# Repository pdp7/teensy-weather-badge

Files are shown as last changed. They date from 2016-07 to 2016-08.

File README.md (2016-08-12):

# teensy-weather-badge
Weather badge with Teensy 3.2 or LC, Adafruit 128x32 OLED (i2c) and Adafruit BME280 (i2c)

## Shared Project:
* [OSH Park: Ab57il2e](https://oshpark.com/shared_projects/Ab57il2e)

## Bill of Materials:
* [Adafruit I2C OLED (128x32)](https://www.adafruit.com/product/931)
* [Adafruit I2C BME280 (temp/hum/press)](https://www.adafruit.com/product/2652)
* Teensy:
   * Option 1: [Teensy 3.2 - OSH Park Edition](https://oshpark.com/teensy)
  * Option 2: [Teensy LC - OSH Park Edition](http://store.oshpark.com/products/teensy-lc)

## Photos:
* [instagram](https://www.instagram.com/p/BHsfERNAH9x/?taken-by=oshpark)
* [twitter](https://twitter.com/pdp7/status/762103242037886977)

## License
This project released under the CERN Open Hardware v1.2 License

**Note:** `teensy-weather-badge.ino` contains code written by Limor Fried & Kevin Townsend for Adafruit Industries and is covered by BSD license

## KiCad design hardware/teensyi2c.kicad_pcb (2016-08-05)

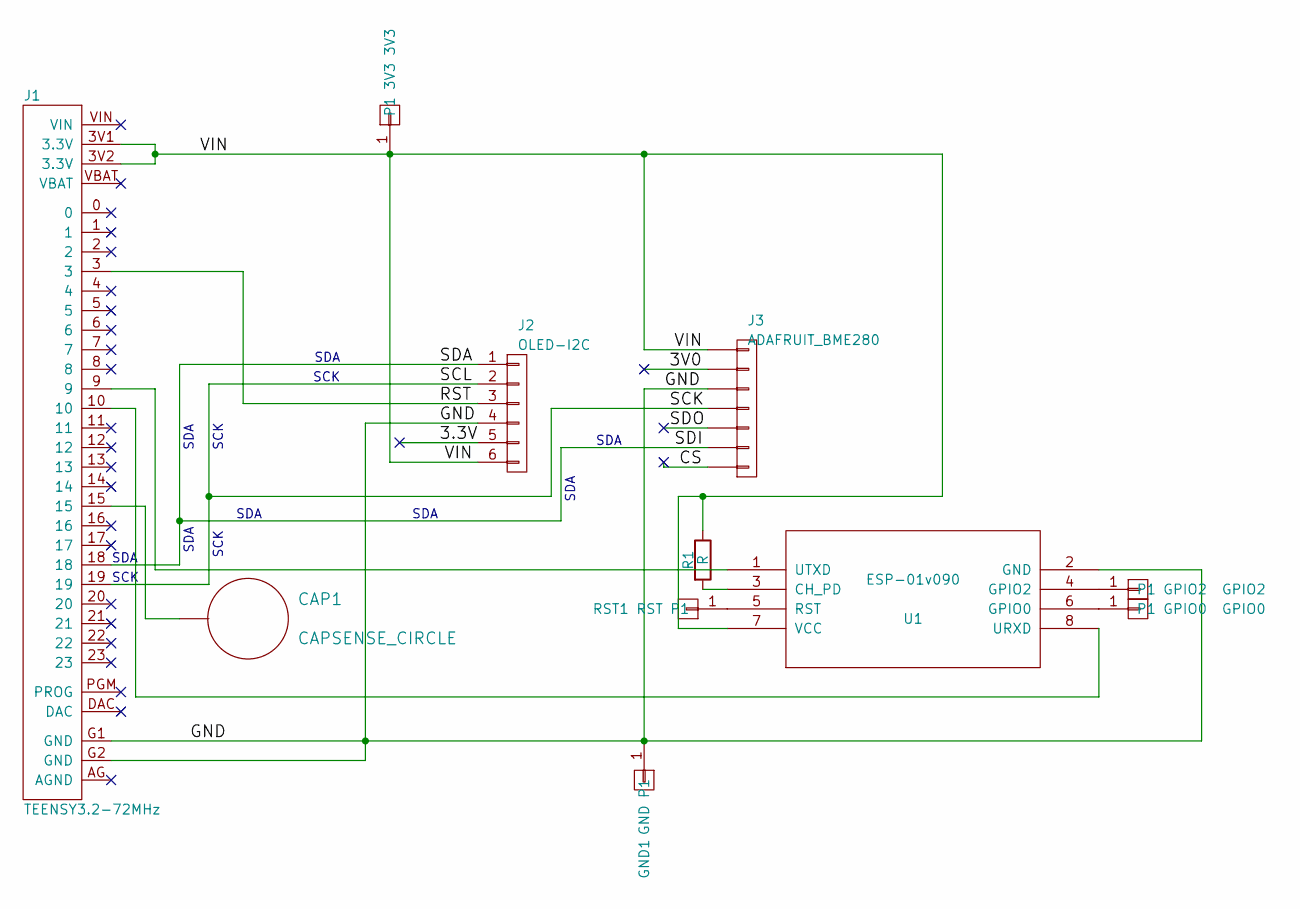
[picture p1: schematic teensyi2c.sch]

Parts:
3V3: 3V3; Pin_Header_Straight_1x01
CAP1: CAPSENSE_CIRCLE; CAPSENSE_CIRCLE_D10
GND1: GND; Pin_Header_Straight_1x01
GPIO0: GPIO0; Pin_Header_Straight_1x01
GPIO2: GPIO2; Pin_Header_Straight_1x01
J1: TEENSY3.2-72MHz; TEENSY-3.2
J2: OLED-I2C; Pin_Header_Straight_1x06
J3: ADAFRUIT_BME280; Pin_Header_Straight_1x07
R1: R; Resistor_Horizontal_RM7mm
RST1: RST; Pin_Header_Straight_1x01
U1: ESP-01v090; ESP-01

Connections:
/3.3V: J2.5
/3V0: J3.2
/CS: J3.7
/GND: GND1.1, J1.G1 (GND), J1.G2 (GND), J2.4, J3.3, U1.2 (GND)
/RST: J1.3, J2.3
/SCK: J1.19, J2.2, J3.4
/SDA: J1.18, J2.1, J3.6
/SDO: J3.5
/VIN: 3V3.1, J1.3V1 (3.3V), J1.3V2 (3.3V), J2.6, J3.1, R1.1, U1.7 (VCC)
unnamed: CAP1.1, J1.15
unnamed: GPIO0.1, U1.6 (GPIO0)
unnamed: GPIO2.1, U1.4 (GPIO2)
unnamed: J1.9, U1.1 (UTXD)
unnamed: J1.10, U1.8 (URXD)
unnamed: R1.2, U1.3 (CH_PD)
unnamed: RST1.1, U1.5 (RST)

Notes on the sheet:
SCK
SDA

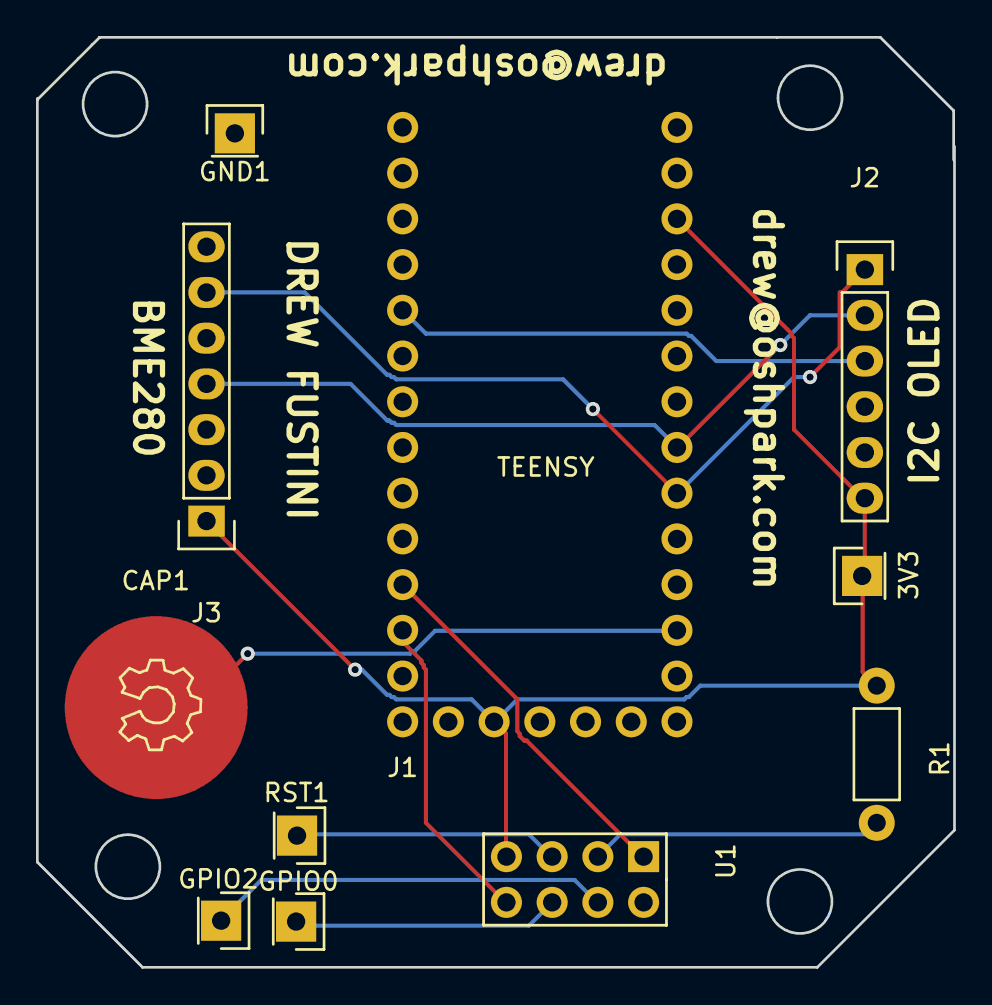
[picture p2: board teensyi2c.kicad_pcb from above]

Board: 2 copper layers, 51.0 x 51.7 mm, 11 parts (0 on the bottom side), 12 nets.

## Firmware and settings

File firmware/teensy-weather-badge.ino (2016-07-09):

/***************************************************************************
  This is a library for the BME280 humidity, temperature & pressure sensor

  Designed specifically to work with the Adafruit BME280 Breakout
  ----> http://www.adafruit.com/products/2650

  These sensors use I2C or SPI to communicate, 2 or 4 pins are required
  to interface.

  Adafruit invests time and resources providing this open source code,
  please support Adafruit andopen-source hardware by purchasing products
  from Adafruit!

  Written by Limor Fried & Kevin Townsend for Adafruit Industries.
  BSD license, all text above must be included in any redistribution
 ***************************************************************************/

#include <Wire.h>
#include <SPI.h>
#include <Adafruit_Sensor.h>
#include <Adafruit_BME280.h>
#include <Adafruit_GFX.h>
#include <Adafruit_SSD1306.h>

#define OLED_RESET 4
Adafruit_SSD1306 display(OLED_RESET);

#define NUMFLAKES 10
#define XPOS 0
#define YPOS 1
#define DELTAY 2

#define BME_SCK 13
#define BME_MISO 12
#define BME_MOSI 11
#define BME_CS 10

#define SEALEVELPRESSURE_HPA (1013.25)

Adafruit_BME280 bme; // I2C
//Adafruit_BME280 bme(BME_CS); // hardware SPI
//Adafruit_BME280 bme(BME_CS, BME_MOSI, BME_MISO,  BME_SCK);

void setup() {

  // by default, we'll generate the high voltage from the 3.3v line internally! (neat!)
  display.begin(SSD1306_SWITCHCAPVCC, 0x3C);  // initialize with the I2C addr 0x3C (for the 128x32)
  // init done
  //display.display();
  //delay(2000);
  display.clearDisplay();

  
  Serial.begin(9600);
  Serial.println(F("BME280 test"));

  if (!bme.begin()) {
    Serial.println("Could not find a valid BME280 sensor, check wiring!");
    while (1);
  }

  // text display tests
  

}

void loop() {
  float temp_c_float = bme.readTemperature();
  int temp_c = round( bme.readTemperature() );
  int temp_f = round( ( (temp_c_float * 9.0) / 5.0 ) + 32.0 );
  int humidity = round ( bme.readHumidity() );
  float hpa = bme.readPressure() / 100.0F;
  float alt = bme.readAltitude(SEALEVELPRESSURE_HPA);
  
  display.clearDisplay();
  display.setCursor(0, 0);
  display.setTextColor(WHITE);
  
  if( temp_f < 100) {
    display.setTextSize(3);
  } else {
    display.setTextSize(2);
  }
  display.print( temp_f );
  display.setTextSize(1);
  display.print("F ");
  display.setTextSize(2);
  display.print( temp_c );
  display.setTextSize(1);
  display.print("C ");
  display.setTextSize(2);
  display.print( humidity );
  display.setTextSize(1);
  display.print("%");

  display.setCursor(0, 25);
  display.print( hpa );
  display.setTextSize(1);
  display.print(" hPa ");
  
  display.print( alt );
  display.setTextSize(1);
  display.println(" m");
  
  display.display();
  
  delay(2000);
}

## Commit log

2016-07-09 Add teensyi2c.kicad_pcb
    From https://oshpark.com/shared_projects/Ab57il2e
    [teensyi2c.kicad_pcb]
2016-07-28 add hardware schematic and layout
    [teensyi2c.sch]
2016-07-28 fix silkscreen
    [teensyi2c.kicad_pcb]
2016-07-28 fix gnd air wire
    [teensyi2c.kicad_pcb]
2016-08-05 fix i2c bus pins
    [teensyi2c.kicad_pcb, teensyi2c.sch]
2016-08-05 add commit and github url to silkscreen
    [teensyi2c.kicad_pcb]
2016-08-05 refill ground plane
